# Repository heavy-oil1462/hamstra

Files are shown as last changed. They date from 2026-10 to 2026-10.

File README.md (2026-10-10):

# Hamstra

Parametric, 3D printable organizers for guns and hunting gear, written in
OpenSCAD. The first set lives in the gun safe and holds on with neodymium
magnets, so nothing is drilled into the safe:

- Suppressor holder: a cradle row the suppressors stand in and a clip row
  above it that they snap into, two short prints
- Spare barrel holder: a base row of cups standing on the safe floor, and
  a separate snap clip for each barrel just below its muzzle. Round
  barrels and over and under barrel sets can share one base row. A
  groove in each cup floor runs out the front, so moisture drains and
  air reaches the breech.
- Gun rack: a comb shelf for the top of the safe

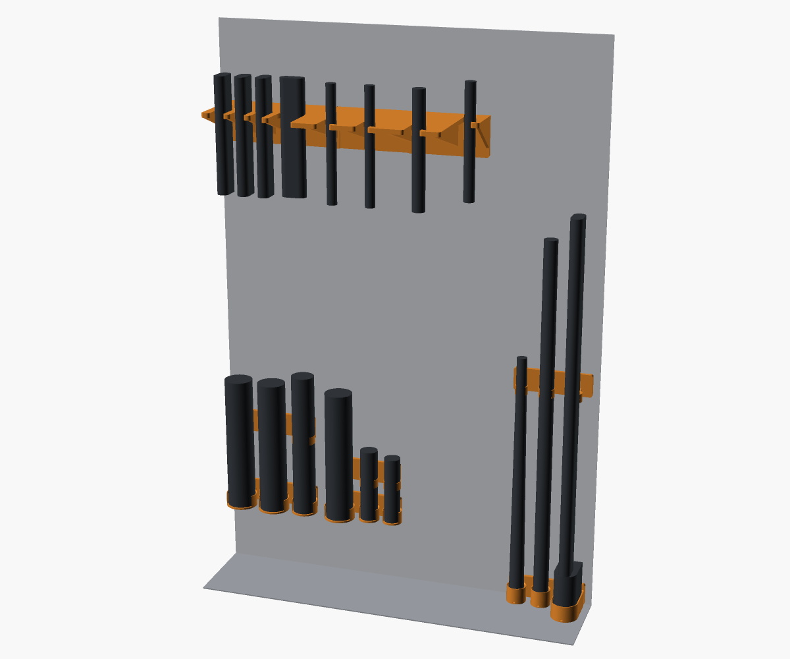
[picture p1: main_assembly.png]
The safe models on a stretch of safe wall with stand-in rifles, barrels and suppressors


Every slot is configured on its own: diameter, distance from the safe
wall and gap to its neighbour. Three break action shotguns can sit tight
to the wall and close together while a scoped bolt action next to them
sits further out with more room.

Every row can also print as separate modules, one per slot, that slide
together with a dovetail like building blocks: smaller prints, and a
slot can be swapped for a different one later.

Reloading equipment and other gear will follow.

Status: early prototypes. Dimensions are still being tuned.

## Models

| Model | File | Prints |
| --- | --- | --- |
| Suppressor holder (cradle and clip) | `cad/safe/suppressor_holder.scad` | upright, as modeled |
| Barrel holder (cup and clip) | `cad/safe/barrel_holder.scad` | upright, as modeled |
| Gun rack | `cad/safe/gun_rack.scad` | shelf down, as modeled |
| Magnet pocket gauge | `cad/calibration/magnet_pocket_gauge.scad` | as modeled |
| Dovetail gauge | `cad/calibration/dovetail_gauge.scad` | as modeled |
| Fit gauge (rings, rack slots, oblong cups) | `cad/calibration/fit_gauge.scad` | flat, as modeled |

None of them need support.

## Customizing

Open a model in OpenSCAD and use the Customizer (Window, Customizer). Every
model lists its knobs there: item diameters, heights, magnet rows and
columns. Measure your suppressor, barrel or breech with calipers and type
the measured diameter in; the models add the clearance themselves.

Per-slot knobs are lists with one entry per slot, and the number of
diameters sets the number of slots:

```
suppressor_d = [50, 44];   // two slots
wall_offset  = [0, 15];    // the second sits 15 mm further from the wall
gaps         = [12];       // 12 mm between them
```

A single number applies to every slot, and a short list repeats its last
entry. The Customizer edits lists of up to four numbers; for more slots
edit the file.

The barrel holder prints as two parts from one file, picked with the
`part` dropdown: the cup and the clip share the slot layout, so each
barrel stands plumb.

## Modular rows

Set `modular = true` and the row prints as one module per slot, each
with its own magnets. Neighbours join with a sliding dovetail on the
plate edges between slots; the outer ends of the row stay plain. Slide
each module down onto the tongue of the one to its left until it stops,
which leaves them level. The gun rack prints upside down, so its joint
is the other way round: mount the rack from the right, and drop each
module's tongue down into the slot of the one to its right.
The gun rack can also group slots into larger modules with
`module_slots`: `[4, 2, 2]` makes three modules of four, two and two
guns, each still within a print bed and with fewer magnets in total.
`scripts/regen_all.py` writes every module to its own STL, numbered
from the left (`gun_rack_modular_1.stl`, ...). With `print_slot = 0` all
modules are laid out side by side for one print; `print_slot = 2` gives
just the second, for reprinting or swapping one slot. `magnets_x` then
counts columns per module.

Print `dovetail_gauge` first and set `dovetail_clearance` to the
tightest slot the key slides into by hand without wobble.

### Your own builds

To keep your own setup, add a small wrapper file that uses a model and
passes your measurements, like `cad/my_safe/suppressors.scad`. Wrapper
files can change the number of slots; OpenSCAD's saved Customizer
presets cannot, because they must keep the list lengths of the model's
defaults. `scripts/regen_all.py` builds wrapper files like any model.

A few values are shared by every model and live in
`cad/design_params.scad` instead: the magnet size and pocket fit, the
back plate thickness and the dovetail joint.

## Fitting your own gear

Before printing a full holder, print `fit_gauge`: thin slices of the real
holder geometry, a few grams each.

- `part = rings`: snap clip rings in a grid, columns stepping the
  clearance and rows stepping the snap opening. Set `ring_d` to the
  measured diameter and press the item into each ring; use the winning
  clearance and snap in the holder. Clip bores are `clip_fit` (in
  design_params.scad) times the diameter, as in the holders: printed
  rings stretch, so they grip well under the item size. A snap of 1 is
  a closed ring at the full diameter and tests the cup and cradle fit.
- `part = slots`: a slice of the gun rack comb with one slot per width.
  Drop each gun's muzzle end in to pick its `slot_w`.
- `part = cups`: slices of a cup for an oblong breech such as an over
  and under monoblock, columns stepping the clearance and rows stepping
  the corner radius of the front end. Many monoblocks are round toward
  the wall and nearly square at the front: a size of `[28, 67, 3]` makes
  the cup match (without the third value both ends are round).

Double guns fit the rack with per-slot widths. A side by side needs a
slot about as wide as both barrels together at the shelf height (often
around 40 mm for a 12 gauge); an over and under needs a slot about one
barrel wide, and stands with the barrels stacked front to back in the
slot. Try both on the slot gauge first.

## Magnets

The defaults use 12x5 mm neodymium disc magnets. Change `magnet_d` and
`magnet_h` in `cad/design_params.scad` for other sizes.

1. Print `magnet_pocket_gauge` first, press a magnet into each pocket and
   set `magnet_clearance` to the tightest one that seats fully.
2. Put a drop of epoxy or CA in each pocket and press the magnet in
   until it stops on the skin at the bottom. With a friction pad it then
   stands `pad_t - pad_air` out of the back (0.7 mm by default).
3. A magnet holds far less sideways on a vertical wall than its rated
   pull, about a quarter: roughly 0.8 kg for a 12x5 magnet on bare
   steel. The defaults give the rows that carry weight (the suppressor
   cradle) about twice the margin they need, and two magnets to rows
   that stand on the floor or only keep items in place. A felt or
   carpet lined safe wall weakens the hold; add magnets there.
4. `python3 scripts/count_magnets.py` counts the magnets your builds
   need.

### Friction pad

A smooth steel wall lets a bare plate slide. Every model has a friction
pad that goes between its back plate and the wall: set `pad = true` in
the Customizer (regen_all exports it as `..._pad.stl`). Either print it
flat in TPU, or print it (or a paper outline of it) as a template and
cut silicone sheet to match. Set `pad_t` in `cad/design_params.scad` to
the pad's thickness before printing the parts: the magnet pockets get
shallower so each magnet reaches through its hole in the pad and stops
`pad_air` short of the wall. The pad takes the friction, the magnets
pull through nothing but air, and the magnets hold the pad in place, so
it needs no glue. Silicone squeezes under the pull more than TPU; give
it a bit more `pad_air`. `pad_t = 0` builds plates with flush magnets
and no pad.

The barrel holder's cup row stands on the safe floor, so its pad output
holds a second piece: a base pad cut to the row's footprint, which goes
under it. It keeps the row from sliding on the floor and lifts the cups
a little off it. No magnet holds it, so the printed TPU version has a
low lip the row sits in (`base_rim_h`). For silicone, use self-adhesive
sheet under the row. `base_pad = false` leaves it out.

## Working on the design

Everything is driven from one script:

```bash
python3 scripts/regen_all.py           # gates, every STL, the assembly image
python3 scripts/regen_all.py --check   # read-only gate, what CI runs
```

It fetches OpenSCAD through nix. Without nix, point `OPENSCAD` at your own
binary. The scripts are standard library Python.

## License

MIT, see `LICENSE`.

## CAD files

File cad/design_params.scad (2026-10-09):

// ============================================================
// HAMSTRA SHARED DESIGN PARAMETERS: single source of truth for
// every dimension two or more models must agree on.
//
// Consumers:
//   - models in cad/<category>/ do   include <../design_params.scad>
//   - libraries in cad/lib/ do       include <../design_params.scad>
//   - scripts/check_params.py FAILS the build if any of these names
//     is re-declared anywhere else. Change values HERE only.
//
// Model-specific knobs (suppressor diameter, slot count, ...) live at
// the top of each model file where the OpenSCAD Customizer shows them.
// Only values that several models share belong here.
//
// Keep this file to simple `name = value;` lines so the tooling can
// parse it. One-off experiments: `openscad -D name=value` beats
// editing this file.
// ============================================================

// --- Mounting magnets (bought) ---
// Neodymium disc magnets glued into pockets in the back face. Nothing
// but air sits between a magnet and the safe wall: pull force collapses
// with any gap, so never bury the magnet behind a printed skin. Holding
// force on a vertical wall is shear, roughly a quarter of the rated pull,
// so count magnets generously.
magnet_d = 12;          // disc diameter
magnet_h = 5;           // disc thickness
magnet_clearance = 0.2; // added to magnet_d for the pocket. MEASURED with
                        // cad/calibration/magnet_pocket_gauge.scad, never
                        // tuned by eye. Printer, profile and filament specific.
magnet_recess = 0;      // extra pocket depth, pulls the magnet face back
                        // from where pad_t and pad_air put it. Without a
                        // pad a bare painted wall can take 0.2 to protect
                        // the paint.
magnet_chamfer = 0.4;   // pocket entry chamfer, eats the elephant foot
magnet_edge = 4;        // minimum plastic from a pocket to the plate edge

// --- Friction pad ---
// A bare plate slides down a smooth steel wall. A pad between plate and
// wall grips it: TPU printed from each model's pad part, or silicone
// sheet cut with that part as the template. The pad has a hole at each
// magnet and the magnets stand out of the back face through it, stopping
// pad_air short of the wall, so the pad carries the magnets' pull and
// takes the friction while only air sits in front of the magnets. The
// magnets also hold the pad in place, no glue needed. A row standing on
// the safe floor (the barrel cup row) gets a second pad under it, cut to
// its footprint: grip on the floor and an air gap under the cups. No
// magnet holds that one, so it has a lip the row sits in, open toward
// the wall where the wall pad is. Silicone cannot make the lip: use
// self-adhesive sheet there.
pad_t = 1;              // pad thickness, 0 for no pad (magnets flush)
pad_air = 0.3;          // magnet face to wall. Soft silicone squeezes,
                        // give it more
pad_hole_clearance = 0.4; // added to magnet_d for the pad's holes
pad_inset = 0.5;        // pad edge inside the plate edge
base_pad_gap = 5;       // a floor standing row's base pad, printed in
                        // front of its wall pad, this far from it
base_rim_h = 2;         // lip the base pad rises around the row's
                        // footprint, so the row sits in it (nothing else
                        // holds the base pad); 0 for a flat pad
base_rim_w = 1.2;       // lip thickness (3 perimeters)
base_rim_clearance = 0.3; // footprint to the inside of the lip
// how far a magnet stands out of the back face
magnet_out = pad_t > 0 ? pad_t - pad_air : 0;

// --- Wall plates ---
// Every safe-mounted model has a flat back plate carrying the magnets.
// One solid plate as thick as a magnet plus its skin, so the front shows
// no trace of the magnets. A skin closes each pocket in front: the magnet
// presses in to it, which sets how far it stands out, and the glue has a
// floor. A magnet standing out for the pad leaves that much more skin. Setting plate_t below back_t gives a lighter plate
// with a boss around each magnet instead.
back_skin = 1.2;                // skin in front of a flush magnet (3 perimeters
                                // at 0.4); 0 runs the pocket through the boss
back_t = magnet_h + magnet_recess + back_skin; // thickness at a magnet (boss)
plate_t = back_t;               // plate thickness away from the magnets
boss_wall = 2;                  // plastic around a pocket in its boss
plate_r = 4;                    // back plate corner radius

// --- Module connector (sliding dovetail) ---
// Modular prints (modular = true in a model) split a row into one module
// per slot. Neighbours join with a symmetric dovetail along the side
// edges of their back plates: tongue on the right edge, slot on the left,
// sliding vertically. The tongue starts on the bed and the slot is
// closed at the far end; tongue and slot end in matching 45 degree
// slopes that meet face to face when the plates are level. Upright prints close the slot at the
// top; the gun rack, printed top down, closes it at the bottom (flip in
// lib/dovetail.scad). 45 degree flanks print without support in either
// orientation. Shared by every model so modules of the same row height
// can mix.
dovetail_d = 2;             // how far the tongue reaches into the neighbour
dovetail_neck = 2.5;        // tongue thickness at its root
dovetail_wall = 1.6;        // plastic in front of and behind the slot
dovetail_clearance = 0.3;   // MEASURED with cad/calibration/dovetail_gauge.scad
dovetail_stop = 3;          // solid plate beyond the joint's sloped end
dovetail_spine_w = 8;       // width of the thickened plate edge carrying the joint
// thickness of that edge: slot plus a wall in front and behind
dovetail_spine_t = dovetail_neck + 2 * (dovetail_d + dovetail_clearance + dovetail_wall);

// --- General print rules ---
wall = 2.4;             // default shell wall (6 perimeters at 0.4)
item_clearance = 1.0;   // added to a gun item's measured diameter for
                        // sleeves and cups it slides into
clip_fit = 0.85;        // snap clip bore as a fraction of the item's
                        // measured diameter. Printed PETG rings stretch a
                        // lot: barrel clips at the barrel size were all too
                        // loose, 15 percent under won a slice test
eps = 0.01;             // cutter overrun, keeps difference() faces apart

$fa = 2;
$fs = 0.4;

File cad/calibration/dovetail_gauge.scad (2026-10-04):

// Dovetail gauge: find dovetail_clearance for your printer, profile and
// filament before printing modular rows.
//
// One key with the tongue and one slotted block per candidate clearance,
// all short slices of the real joint (same profile, same spine). Slide
// the key down into each block from the open bottom. Pick the tightest
// clearance that slides home by hand without wobble and type it into
// design_params.scad. Prints standing as modeled, like the upright models.

include <../design_params.scad>
use <../lib/dovetail.scad>

clearances = [0.1, 0.2, 0.3, 0.4];

gauge_h = 20;               // joint length
gauge_w = 14;               // block width
gauge_pitch = gauge_w + dovetail_d + 6;

module label(txt) {
    translate([gauge_w / 2, -dovetail_spine_t / 2, gauge_h - 0.6])
        linear_extrude(0.6 + eps)
            text(txt, size = 3.5, halign = "center", valign = "center");
}

// Same joint as dovetail_female, but with clearance c and a full-length
// slot so it reads at a glance which one fits.
module gauge_slot(c) {
    translate([0, 0, -eps]) linear_extrude(gauge_h + 2 * eps) dovetail_profile(c);
}

module dovetail_gauge() {
    // the key: a block with the tongue on its right edge
    translate([-gauge_pitch, 0, 0]) {
        translate([0, -dovetail_spine_t, 0]) cube([gauge_w, dovetail_spine_t, gauge_h]);
        translate([gauge_w, 0, 0]) linear_extrude(gauge_h) dovetail_profile();
    }
    for (i = [0 : len(clearances) - 1])
        translate([i * gauge_pitch, 0, 0])
            difference() {
                translate([0, -dovetail_spine_t, 0]) cube([gauge_w, dovetail_spine_t, gauge_h]);
                gauge_slot(clearances[i]);
                label(str(clearances[i]));
            }
}

dovetail_gauge();

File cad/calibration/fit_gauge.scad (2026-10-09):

// Fit gauge: cheap test slices of the real holder geometry, to find the
// diameters, clearances and snap openings that hold your own suppressors,
// barrels and rifles before printing full holders. No back plate, no
// magnets, a few grams each.
//
//   rings  a grid of thin snap clip slices: columns step the clearance,
//          rows step the snap opening (fraction of the clip bore). A
//          clip ring's bore is ring_d times clip_fit plus the clearance,
//          as in the holders. A snap of 1 or more prints a closed ring at
//          ring_d plus the clearance, which tests the fit of a cup or
//          cradle. Measure the item, set ring_d, press the item into each
//          ring. Use the winning clearance and snap in the model.
//   slots  a thin slice of the gun rack comb with one slot per width,
//          made by the rack's own profile code. Drop the muzzle end of
//          each gun into the slots to pick its slot_w.
//   cups   thin slices of a cup bore for an oblong breech (an over and
//          under monoblock), wall toward the label tab: columns step
//          the clearance, rows step the front corner radius (half the
//          width = round). Push the breech in from the top, back to the
//          tab, and use the winning [width, depth, radius] and clearance
//          in the model. cup_gauge() is also used by cad/my_safe.
//
// Every ring and slot is labelled. Prints flat as modeled.

include <../design_params.scad>
use <../lib/holders.scad>
use <../safe/gun_rack.scad>

// Which gauge to show
part = "rings"; // [rings, slots, cups]

/* [Rings] */
// Measured diameter of the suppressor, barrel or breech
ring_d = 50;
// Clearances to try, added to the bore (one column each)
clearances = [0.2, 0.6, 1.0];
// Snap openings to try as a fraction of the clip bore, 1 = closed (one row each)
snaps = [0.8, 0.85, 0.9, 1];
// Ring wall, as clip_wall in the models
ring_wall = 3;
// Ring height
ring_h = 5;

/* [Rack slots] */
// Slot widths to try
slot_widths = [20, 22, 38, 42];
// Finger between slots
slot_gap = 10;
// Slot depth
slot_depth = 30;
// Gauge thickness
slot_t = 4;

/* [Cup slices] */
// Oblong breech to test, measured: [width along the wall, depth]
cup_shape = [30, 60];
// Front corner radii to try, one row each (half the width = round)
front_radii = [15, 6, 2];
// Clearances to try, added like item_clearance (one column each)
cup_clearances = [0.6, 1.0, 1.4];
// Slice height
cup_h = 4;

label_size = 3.5;
label_depth = 0.6;

module label(txt) {
    linear_extrude(label_depth + eps)
        text(txt, size = label_size, halign = "center", valign = "center");
}

// One clip slice: the bore and snap opening of holder_row, a label tab
// where the web would meet the back plate. Also used by cad/my_safe.
module gauge_ring(d, c, s, ring_wall = ring_wall) {
    fd = s < 1 ? d * clip_fit : d;
    r = (fd + c) / 2;
    tab = [22, 13];
    difference() {
        union() {
            cylinder(r = r + ring_wall, h = ring_h);
            translate([-tab[0] / 2, r, 0]) cube([tab[0], tab[1], ring_h]);
        }
        translate([0, 0, -eps]) cylinder(r = r, h = ring_h + 2 * eps);
        if (s < 1) snap_opening(r, ring_wall, fd * s, -eps, ring_h);
        translate([0, r + ring_wall + 6.5, ring_h - label_depth]) label(str("c", c));
        translate([0, r + ring_wall + 1.5, ring_h - label_depth]) label(str("s", s));
    }
}

module ring_gauge() {
    pitch_x = ring_d + max(clearances) + 2 * ring_wall + 4;
    pitch_y = ring_d + max(clearances) + ring_wall + 13 + 4;
    for (i = [0 : len(clearances) - 1], j = [0 : len(snaps) - 1])
        translate([i * pitch_x, j * pitch_y, 0])
            gauge_ring(ring_d, clearances[i], snaps[j]);
}

// One cup slice: the holder_row bore of shape s grown by c, wall thick,
// with a label tab on the wall side.
module gauge_cup(s, c, h = cup_h) {
    g = grow(s, c);
    tab = [22, 13];
    difference() {
        union() {
            linear_extrude(h) offset(r = wall) bore2d(g);
            translate([-tab[0] / 2, sy(g) / 2, 0]) cube([tab[0], tab[1], h]);
        }
        translate([0, 0, -eps]) linear_extrude(h + 2 * eps) bore2d(g);
        translate([0, sy(g) / 2 + wall + 6.5, h - label_depth]) label(str("c", c));
        translate([0, sy(g) / 2 + wall + 1.5, h - label_depth]) label(str("r", s[2]));
    }
}

// Grid of cup slices for an oblong [width, depth]: a column per
// clearance, a row per front corner radius.
module cup_gauge(shape = cup_shape, radii = front_radii, clearances = cup_clearances,
                 h = cup_h) {
    assert(is_list(shape), "cup_shape is [width, depth]");
    pitch_x = sx(shape) + max(clearances) + 2 * wall + 4;
    pitch_y = sy(shape) + max(clearances) + wall + 13 + 4;
    for (i = [0 : len(clearances) - 1], j = [0 : len(radii) - 1])
        translate([i * pitch_x, j * pitch_y, 0])
            gauge_cup([shape[0], shape[1], radii[j]], clearances[i], h);
}

module slot_gauge() {
    ws = slot_widths;
    n = len(ws);
    base = 10;   // strip under the deepest slot, carries the labels
    edge = slot_gap;
    xs = slot_xs(ws, slot_gap, edge);
    l = xs[n - 1] + ws[n - 1] / 2 + edge;
    depth = base + max(ws) / 2 + slot_depth;
    difference() {
        linear_extrude(slot_t)
            comb_profile([[0, l, depth]], ws, xs, [for (w = ws) base], 3);
        for (i = [0 : n - 1])
            translate([xs[i], base / 2, slot_t - label_depth]) label(str(ws[i]));
    }
}

if (part == "rings") ring_gauge();
else if (part == "slots") slot_gauge();
else if (part == "cups") cup_gauge();
else assert(false, str("unknown part: ", part));

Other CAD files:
cad/calibration/magnet_pocket_gauge.scad
cad/main_assembly.scad
cad/my_safe/barrels.scad
cad/my_safe/rifles.scad
cad/my_safe/suppressor_clip_test.scad
cad/my_safe/suppressors.scad
cad/safe/barrel_holder.scad
cad/safe/gun_rack.scad
cad/safe/suppressor_holder.scad

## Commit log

2026-10-04 Project scaffold and first draft gun safe models
    Boilerplate modeled on skua: design_params.scad as the single source of
    shared values, check_params.py guarding it, regen_all.py as the one
    pipeline entry point with --check as the read-only verify gate, the
    headless nix render helper, the verify, regen-outputs and
    openscad-review skills, and the CI workflow running the same gate.
    First drafts of the safe models, all configurable through Customizer
    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
    [barrel_clip.scad, barrel_cup.scad, design_params.scad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]
2026-10-04 Per-slot diameter, wall offset and gap for every holder and the rack
    Each multi-slot model now takes per-slot lists: diameter (slot width on
    the rack), wall_offset (extra distance from the safe wall, 0 = tight)
    and gaps (edge to edge per neighbouring pair). A single number or a
    short list also works, the last entry repeats. The rack default shows
    the point: three break actions tight and close, a scoped bolt action
    set out from the wall with a wide gap.
    The barrel cup and clip merge into barrel_holder.scad with a part
    dropdown so one slot layout drives both; regen_all exports one STL per
    dropdown option. barrel_pitch and barrel_axis_y leave design_params.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
    [barrel_clip.scad, barrel_cup.scad, barrel_holder.scad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]
2026-10-04 Suppressor holder: tall plate, floor cradle and top snap clip
    The short sleeve could not hold a suppressor upright. Now each
    suppressor stands on the floor plate of a cradle at the bottom and
    snaps into a clip near the top (clip_top), on one tall back plate,
    cradle and clip sharing the barrel holder's pair layout so it stands
    plumb.
    A clip high on an upright plate cannot print without support, so the
    holder prints lying on its back like the gun rack: cradle and clip
    become open troughs, snap arms curl in under 45 degrees. Magnet
    pockets on the bed side lose the teardrop roof (wall_mount teardrop
    flag). The snap opening now starts above the floor so floors stay
    whole.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
    [barrel_holder.scad, main_assembly.scad, suppressor_holder.scad]
2026-10-04 Modular rows: one module per slot, joined with a sliding dovetail
    modular = true prints a row as one module per slot instead of one
    piece. Modules split at the middle of each gap, so a joined row keeps
    the one-piece layout, and each carries its own magnets. Neighbours join
    with a symmetric 45 degree dovetail along the plate side edges (tongue
    right, slot left, slot closed at the top so modules stop level), which
    prints without support both upright and on the back. print_slot picks
    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
    [barrel_holder.scad, design_params.scad, dovetail_gauge.scad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]
2026-10-04 Dovetails only between slots, and one STL per module
    The outer ends of a modular row stay plain: the first module has no
    slot on its left edge, the last no tongue on its right, and neither
    gets the thickened edge there, so their outer corners stay rounded.
    The joint parts take joints = [left, right] instead of an all or
    nothing flag.
    regen_all now exports every module of a modular model to its own STL
    (<name>[_<part>]_modular_<n>.stl) instead of one file with all modules
    laid out. The module count comes from the model's echo(modules = n)
    in a cheap echo-only pass, so it always follows the slot lists. Every
    export sets modular explicitly, so the file default no longer matters.
    Co-Authored-B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
    [gun_rack.scad]
2026-10-04 Fit gauge: cheap slices of the real clips and rack slots
    cad/calibration/fit_gauge.scad prints test slices of the holder
    geometry with no plate or magnets, a few grams each, so suppressors,
    barrels and rifles can be fitted before printing full holders:
    - rings: a grid of snap clip slices, clearance per column, snap
    opening per row, each labelled; snap 1 is a closed ring for cup and
    cradle fit
    - slots: a slice of the gun rack comb, one labelled slot per width,
    cut by the rack's own comb_profile
    README notes how double guns fit the rack: side by side wants a slot
    about two barrels wide, over and under about one.
    [fit_gauge.scad]
2026-10-04 Per-slot clip height, and the first my_safe build: suppressors
    clip_top in the suppressor holder is now per slot like the other slot
    knobs, since one row can hold a 130 mm rimfire can next to 265 mm
    ones; the tallest clip sets the plate height.
    cad/my_safe/suppressors.scad builds the holder for four measured
    suppressors (45 x 230.7, 45 x 230.7, 41 x 265, 31.5 x 130 mm) as a thin
    wrapper around the generic model. A Customizer preset cannot do this:
    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
    [suppressor_holder.scad, suppressors.scad]
2026-10-04 Assembly shows the my_safe suppressors
    The scene's suppressor holder is now the cad/my_safe build, with
    stand-ins at the measured diameters and lengths, instead of scene
    values. Nothing is copied: the wrapper hands its knobs to the scene
    through my_suppressors_data() and a my_suppressors() module, and the
    stand-ins are placed with suppressor_layout(), the function the
    holder itself now uses. The wrapper records suppressor lengths for
    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
    [main_assembly.scad, suppressor_holder.scad, suppressors.scad]
2026-10-04 Barrel holder: floor-standing bases, separate clips, oblong slots
    The cup row now stands on the safe floor and carries the barrels'
    weight there (one flat bottom, 3 mm floors, no drain hole by default);
    its magnets only hold it to the wall, since safe walls are too
    slippery to hang barrels on.
    Barrels differ in length, so each clip is its own piece by default,
    mounted just below its muzzle straight above its cup; clip_row = true
    joins them for barrels of about the same length. wall_row gains a
    joined flag for pieces that mount on their own.
    Holder slot sizes can be [width, depth] as well as a diameter, for an
    over and under barrel set stacked front to back. Round and oblong
    slots mix in on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
    [barrel_holder.scad, barrels.scad, main_assembly.scad]
2026-10-04 my_safe barrels: real lengths in the scene
    Barrel 1 is the 660 mm (26 inch) SSG 3000 / STR 200 drop-in from its
    spec, barrel 2 about 450 mm (estimate). The scene moves the barrel
    block right of the gun rack so the long barrel and its clip clear it.
    [barrels.scad, main_assembly.scad]
2026-10-04 Suppressor holder in two pieces: cradle row and clip row
    One tall plate took long to print. The holder is now a cradle row low
    on the wall and a clip row mounted above it, both short and printed
    upright from one slot layout, picked with a part dropdown. All clips
    share one height, so they form one row (clip_row, as on the barrel
    holder); a clip low enough for the short .22 can still holds the long
    ones, so clip_top leaves the model and becomes the mounting height in
    the my_safe build (80 mm), used by the scene.
    The barrel and suppressor holders were the same cup and clip pair with
    different defaults, so the pair now lives once as cup_clip_part in
    lib/holders.scad and both models call it.
    C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
    [barrel_holder.scad, main_assembly.scad, suppressor_holder.scad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]
2026-10-04 B25 over and under set joins the my_safe barrels, flush to the wall
    The B25 barrel set is the third slot in the barrel base row: an oblong
    28 x 67 mm cup for its monoblock and an oblong clip for the two 21 mm
    barrels. Its length in the scene (710 mm) is an estimate.
    New per-slot clip_align on the barrel holder: 0 keeps the clip centered
    over the cup (tapered round barrels), 1 puts the clip's back flush with
    the cup's back. The B25 barrels run flush with the back of the deeper
    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
    [barrel_holder.scad, barrels.scad, main_assembly.scad]
2026-10-04 my_safe barrels: one joined clip row at 400 mm
    All three barrels share one clip row mounted 400 mm above the cup
    floor, just below the shortest muzzle and above every barrel's center
    of mass. The clips are sized for the diameter at that height: the B25
    barrels are straight (21 mm), the two rifle barrels are straight-taper
    estimates (25.2 mm on the M24 contoured Jury barrel, 18.6 mm) to be
    confirmed with the fit gauge. Measured muzzle sizes stay in the build
    for the scene's stand-ins.
    Docs now name 12x5 mm as the default magnet, matching magnet_h = 5.
    [barrel_holder.scad, barrels.scad, main_assembly.scad]
2026-10-04 my_safe rifles: an eight gun rack, tight break actions, room for bolts
    cad/my_safe/rifles.scad builds the gun rack for the current long guns,
    left to right: Miroku, Tikka and B25 over and unders and a 12 ga side
    by side packed tight to the wall on 12 mm fingers (no bolts), then the
    Sauer 202, Tikka T3 Lite, Bergara B14R and AR15-22 with wide gaps on
    their left for bolts and wall offsets for scopes, the Bergara's Razor
    the most. Slots are open (guns lean in), barrel width plus 4 mm. The
    rack is wider than a print bed, so the build defaults to modular, one
    module per gun (largest 78 x 99 mm on the bed). T3 and AR barrel sizes
    and the rack height in the scene are placeholders.
    gun_rack exposes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
    [gun_rack.scad, main_assembly.scad, rifles.scad]
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2026-10-04 my_safe rifles: rack shelf at 560 mm, below the Bergara's muzzle
    The Bergara (61 cm overall) is the shortest gun for now, so the scene
    puts the shelf top 5 cm below its muzzle. The scene's wall grows and the
    barrel block moves right of the rack so the long barrels clear it.
    [main_assembly.scad, rifles.scad]
2026-10-04 my_safe rifles: the Bergara is 91 cm overall, shelf top at 860 mm
    [main_assembly.scad, rifles.scad]
2026-10-04 my_safe rifles: the Bergara is 96 cm overall; shelf stays at 860 mm
    [rifles.scad]
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2026-10-04 Efficiency pass: thin plates with magnet bosses, per-slot shelf, magnets by load
    Measured on the my_safe builds: plastic down from 872 to 654 cm3
    (about 25 %), magnets from 48 to 18, rack modules for the break
    actions 23 to 36 mm shorter to print.
    - Back plates are 3 mm (plate_t) with a full back_t boss only around
    each magnet; the back face stays flat on the wall. Bosses on upright
    prints come to a 45 degree point underneath, so no support.
    - Rack shelf depth is per slot (wall offset plus slot_depth) instead of
    the deepest slot's depth across the whole rack; a finger takes its
    deeper neighbour's depth so steps fall on slot edges and joints stay
    flush.
    - Magnet counts follow the l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
    [barrel_holder.scad, design_params.scad, fit_gauge.scad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]
2026-10-04 Magnet bosses only as thick as the magnet, pockets run through
    back_skin goes to 0: the boss around each magnet is 5 mm, the magnet's
    own thickness, and the pocket runs through it (cut past the face so no
    coplanar faces). Magnets are glued in flush with the back against a
    flat surface. Holders sit 2 mm closer to the wall; rack slot bottoms
    now clear the dovetail edge strip explicitly, so the rack layout stays
    put. Plastic on the my_safe builds: 654 -> 632 cm3.
    [design_params.scad, gun_rack.scad]
2026-10-04 Magnet bosses get a 1.2 mm skin to glue and index against
    The through pockets were awkward to mount. A 1.2 mm skin (three
    perimeters at 0.4) closes each pocket in front: the magnet presses in
    to a stop that leaves it flush with the back, and the glue has a floor.
    Bosses are 6.2 mm instead of the original 7. Plastic on the my_safe
    builds: 645 cm3.
    [design_params.scad]
2026-10-04 Solid back plates: no trace of the magnets on the front
    plate_t now equals back_t, the magnet plus its 1.2 mm skin (6.2 mm), so
    plates are one solid thickness and the bosses drop out. A plate_t
    below back_t still gives the lighter thin plate with bosses. Plastic on
    the my_safe builds: 767 cm3 (thin plates were 645, the original solid
    7 mm plates 872).
    [design_params.scad]
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2026-10-04 check_joints.py: gate that neighbouring modules never overlap
    The joint fit test was done by hand several times; now it is a script.
    It intersects every pair of neighbouring module STLs and fails above
    0.01 mm3 of shared volume (only the joint plane may touch). regen_all
    runs it after the STL stage, on the temp dir in --check, so verify and
    CI gate it. All 24 joints in the current builds measure 0.
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2026-10-04 Measured dovetail clearance 0.3, magnets 12x5
    The dovetail gauge printed in PETG on the Qidi Q2 fit best at 0.3.
    The magnets delivered are 12x5, not 15x5. Smaller pockets fit a second
    row on the suppressor cradle, so it goes from 4 to 8 magnets and keeps
    its margin at about 0.8 kg shear per magnet.
    [design_params.scad]
2026-10-04 Clip rows get their own magnet row count
    Clip rows only keep items in, so they no longer follow the load
    carrying row's magnets_z. clip_magnets_z defaults to 1, which takes the
    suppressor clip row back to 2 magnets (22 in total for my_safe).
    [barrel_holder.scad, suppressor_holder.scad]
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2026-10-04 README image from the assembly scene
    main_assembly.png is now committed and shown in the README. regen_all
    renders it from a fixed front three-quarter view (ASSEMBLY_VIEW) with
    a light steel wall and dark stand-ins, so the printed parts stand out.
    OpenSCAD has no antialiasing and the sandbox has no image library, so
    render_scad.py gains --supersample=N: render N times larger and average
    down in plain Python.
    The scene gets a show_wall toggle and one color each for printed parts
    and stand-ins.
    [main_assembly.scad]
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2026-10-05 Friction pad between back plate and wall, magnets reach through it
    Every model gets a pad = true output: the plate outline with a hole per
    magnet, printed flat in TPU or used as the template for silicone sheet.
    pad_t and pad_air in design_params set the pad thickness and the air
    left in front of each magnet. Pockets get shallower by magnet_out, so
    the skin grows and the plate keeps its thickness, and the magnets stand
    through the pad to stop pad_air short of the wall. The pad carries the
    pull and takes the friction, the magnets hold it without glue.
    pad_t = 0 gives the old flush magnets. regen exports a _pad STL for
    every part and module.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
    [barrel_holder.scad, barrels.scad, design_params.scad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]
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2026-10-05 Gun rack dovetail starts on the bed, slot ends get a 45 degree roof
    The rack prints shelf down, so the plate's top edge is on the bed, but
    the tongue stopped dovetail_stop short of that edge and started 3 mm
    above the bed with nothing under it. dovetail_joints and dovetail_cuts
    take flip = true, which mirrors the joint about mid height: on the rack
    the tongue now runs from the bed (z 0 to 67, was 3 to 70) and the slot
    closes at the plate bottom. Mount the rack right to left, dropping each
    module's tongue into its right neighbour's slot.
    The slot's closed end was a flat ceiling over the slot in both
    orientations; it is now a 45 degree roof closing in on the plate edge,
    so it prints without b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
    [design_params.scad, gun_rack.scad]
2026-10-05 Dovetail tongue ends in a 45 degree slope matching the slot
    Only the tongue's square corner touched the slot's sloped end, and the
    slot sat a clearance long as well, so a module seated about 0.6 mm
    below level and the corner could wedge. Tongue and slot now end in the
    same 45 degree slope (dovetail_end), the slot's a clearance lower, so
    the two slopes meet face to face exactly when the plates are level.
    Sliding a slot piece down onto a tongue piece: no overlap at level,
    0.45 mm3 at 0.05 mm past it (first contact was at 0.7 mm before).
    [design_params.scad]
2026-10-05 Dovetail ends cut by a 45 degree plane, flanks straight
    The previous commit built the sloped ends with hull(), which fills the
    dovetail's narrow neck: the tongue's end came out wider than the slot
    and jammed over the whole slide (0.22 mm3 overlap from 20 mm above
    level down). The ends are now the dovetail section cut by the plane
    x + z = k (dovetail_bar), so the flanks stay as profiled and tongue and
    slot still meet face to face when the plates are level. Slide test
    from 30 mm above level: no overlap until level, 0.45 mm3 at 0.05 mm
    past it. The tongue starts on the bed, only the slot cutter overruns.
    openscad-review notes: hull() of a non-convex profile, and test a
    sliding fit over its who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
2026-10-05 My barrels: short 9.3 first, then 6 mm Creedmoor, then the B25
    Swaps slots 1 and 2 in every per-slot list of the barrel build (clip
    size, muzzle, length; the breech sizes are equal) and names the
    barrels in the header. Wall offsets, gaps and clip alignment are the
    same for both slots, so the layout is otherwise unchanged.
    [barrels.scad]
2026-10-05 Oblong slots take a front corner radius, cup fit gauge for the B25
    An oblong slot size may add a third value, the corner radius of its
    front end: [28, 67, 3] is round toward the wall and nearly square at
    the front, like an over and under monoblock. Without it both ends stay
    round, so every existing slot is unchanged (main_assembly.png renders
    byte for byte the same). grow() carries the radius, a radius of half
    the width or more is the round end.
    fit_gauge gets part = cups: thin cup slices for an oblong breech, a
    column per clearance and a row per front corner radius, built from the
    holder's own bore2d. cad/my_safe/b25_gauge.scad prints them for the
    B25 monoblock, 28 x 67, radii 14 (round, a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
    [b25_gauge.scad, fit_gauge.scad]
2026-10-05 B25 gauge: drop the round row, it visibly does not fit
    [b25_gauge.scad]
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2026-10-05 My barrels: B25 cup square at the front, roomiest gauge slice
    The cup only locates the monoblock, so skip the gauge and use the
    roomiest slice it would have offered: 1 mm front corner radius and
    1.4 mm total clearance (item_clearance 1.0 plus 0.4 in the size),
    breech_d [28.4, 67.4, 1]. Drops cad/my_safe/b25_gauge.scad; the
    generic fit_gauge cups part stays.
    [b25_gauge.scad, barrels.scad]
2026-10-05 Barrel cups get their own loose cup_clearance, 3 mm
    Barrel cups used the shared item_clearance (1.0, 0.5 mm a side), a
    locating fit tighter than they need. The barrel holder now has its own
    cup_clearance, default 3 (1.5 mm a side): the cup only locates the
    breech, the clip keeps the barrel plumb, and the room lets air around
    the breech. item_clearance stays for the suppressor cradles. The B25
    goes back to its measured [28, 67, 1]. Sliced the printed cup row:
    round cups 34.8 outside (30 bore), the B25 35.8 (31 bore).
    [barrel_holder.scad, barrels.scad]
2026-10-06 Barrel holder: wider B25 cup, figure 8 B25 clip, clip test prints
    The first B25 cup was sized for a 28 mm monoblock; the barrel set is 40
    mm at its widest. The B25 clip becomes a figure 8 (eight() in
    lib/holders.scad) with a waist that traps the inner barrel and a
    smaller outer lobe that wraps the outer one. The printed clips were all
    too loose, so barrel_clip_test.scad prints three sizes per barrel from
    the real clip geometry. count_magnets leaves *_test files out.
    [barrel_clip_test.scad, barrel_holder.scad, barrels.scad]
2026-10-06 Round barrel clips 20 percent under the barrel, tests at 15/20/25
    The printed rings stretch a lot, so an undersized clip still snaps on
    and grips. The 9.3 and 6 mm Creedmoor clips go to the middle test size.
    [barrel_clip_test.scad, barrels.scad]
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2026-10-09 Suppressors in two sets of three, Stalon X108 added
    Set 1 holds the long 45, 45 and 41 cans, set 2 the X108 and the two
    short .22 cans. Each set is its own cradle row and clip row, picked
    from the part dropdown (cradle_1, clip_1, cradle_2, clip_2), so the
    export needs no change. Set 1 clips at 150 mm now that the .22 cans no
    longer set its height; set 2 stays at 80. X108 at its listed size,
    49.1 x 235, until it is measured.
    [main_assembly.scad, suppressors.scad]
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2026-10-09 Suppressor clips 15 percent under the can, Victor L at 41 x 258
    The barrel clip slice test showed printed rings stretch a lot: clips at
    the barrel size were too loose, 15 percent under won. The suppressor
    holder gets clip_fit = 0.85 for its clip bore, and the snap opening
    scales from that bore as on the barrel clips. The 41 mm can is a Victor
    L, 258 long per the official spec.
    [suppressor_holder.scad, suppressors.scad]
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2026-10-09 One clip_fit for barrel and suppressor clips
    The tested barrel clips were all about 15 percent under the barrel.
    clip_fit = 0.85 in design_params.scad now sets every snap clip bore
    from the measured diameter: barrel holder, suppressor holder and the
    fit gauge's clip rings. barrels.scad lists the measured barrel sizes
    again; the bores land within 0.15 mm of the tested ones.
    [barrel_holder.scad, barrels.scad, design_params.scad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]
2026-10-09 One ring clip test for the W110 and the Victor L
    A 5 mm slice of each set 1 suppressor clip, made by the fit gauge's ring
    with the suppressor holder's clearance, snap and wall, to check the
    clip_fit grip on the cans before printing the full clip row.
    [fit_gauge.scad, suppressor_clip_test.scad, suppressor_holder.scad]
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2026-10-10 Rifle rack wall offsets from measured scope clearance
    All four doubles get a 75 mm wall to barrel gap, so any of them fits
    any of slots 1 to 4 and scopes can change. The Bergara measured 100 mm
    minimum, set to 110. The gap is wall_offset plus 12.3 mm (slot bottom
    plus pad).
    [rifles.scad]
2026-10-10 Group rack slots into modules, my rack in three
    gun_rack gets module_slots: slots per module, one number or a list
    covering every slot. Default 1 keeps one module per slot. My rack
    prints as [4, 2, 2] with two magnets per module, 6 magnets instead of
    8. Four bolt gun slots in one module would be 268.5 mm wide, too tight
    for the 270 mm bed.
    regen_all now deletes module STLs a model no longer makes, so the joint
    gate never compares a new module with a stale one.
    [gun_rack.scad, rifles.scad]
2026-10-10 Suppressor back plate 10 mm shorter at both ends
    suppressor_holder gets plate_trim: the back plate ends that much inside
    the outer holders, which then overhang it. Magnets move in with the
    ends. My suppressor rows use 10 mm, so the plate of set 1 is 154 mm
    instead of 174. The cups and clips are unchanged.
    [suppressor_holder.scad, suppressors.scad]
2026-10-10 Suppressor plate ends flush with the outer webs
    plate_trim cut a flat 10 mm from both ends, which left a small step
    against the outer webs: the webs are 70 percent of each bore wide, so
    the 50 mm can on the left and the 41 mm can on the right end in
    different places. plate_to_webs replaces it and ends each piece's plate
    exactly at its own outer webs, cradle and clip separately. The plate's
    bottom corners then stay square ($square_bottom in plate2d), so the end
    is one flat face down to the bed instead of a rounded notch.
    holder_web_w is now the one place the web width lives.
    [suppressor_holder.scad, suppressors.scad]
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
